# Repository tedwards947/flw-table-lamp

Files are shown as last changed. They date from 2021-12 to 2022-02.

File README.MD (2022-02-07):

# Intro
This is my 3D printed take on the Frank Lloyd Wright table lamp he designed for his house Taliesin in Wisconsin. I was inspired by seeing a wooden one in an art museum's gift shop. It was pretty but I didn't want to spend the $ to buy it, so my dad said, "Why don't you just make one?"--so I did! I didn't use any original drawings to help me with this design--it's a reverse engineering and re-imagining using 3D printed plastic instead of wood.

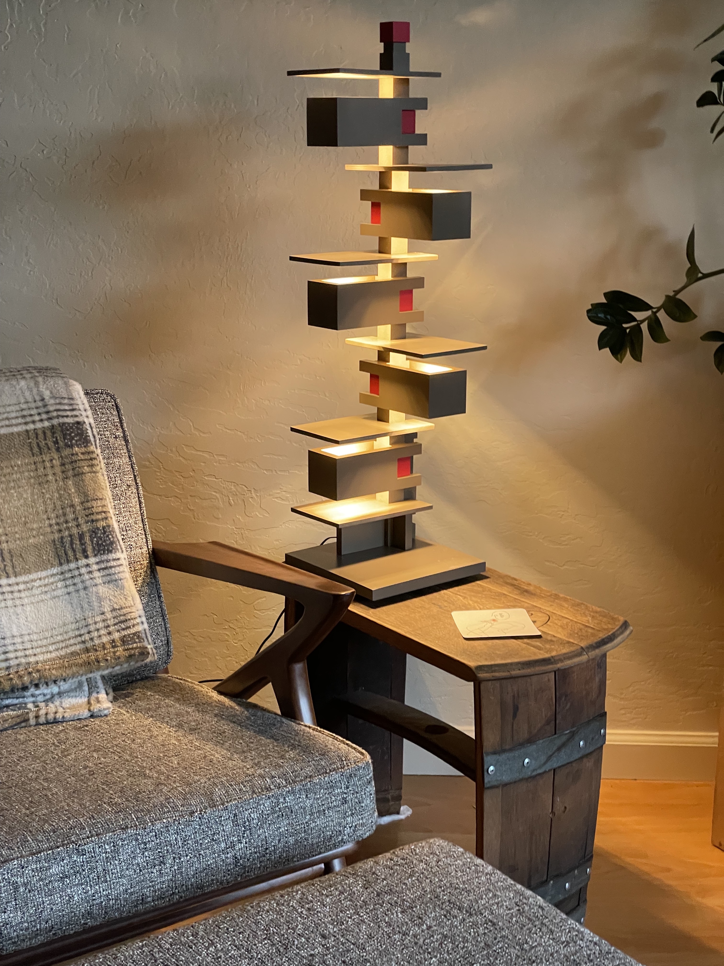
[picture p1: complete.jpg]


# Print Orientation
Here are the various parts you'll need to print, facing the orientation best suited for printing.

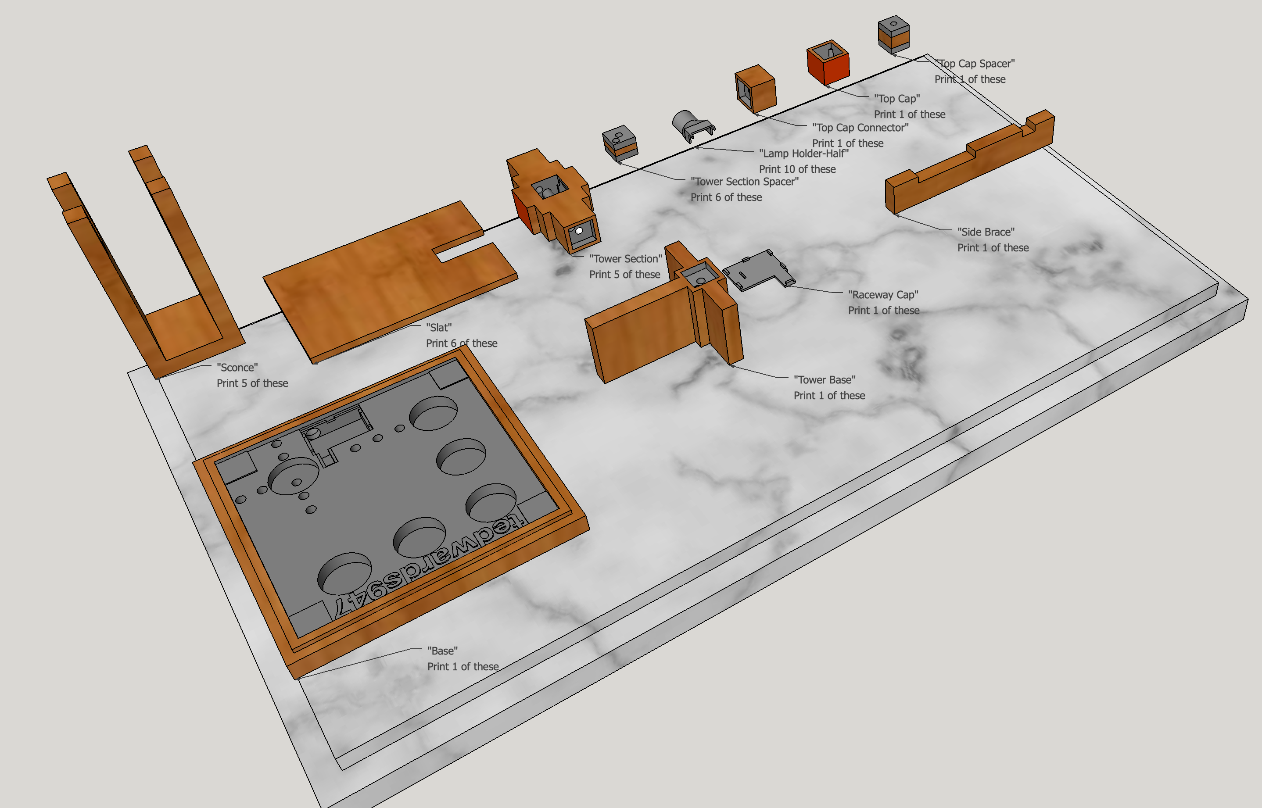
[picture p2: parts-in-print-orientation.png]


# Parts
Print the following number of each part:
<table>
    <tr><td><b>Part</b></td><td><b>Number</b></td></tr>
    <tr><td>Sconce</td><td>5</td></tr>
    <tr><td>Slat</td><td>6</td></tr>
    <tr><td>Tower Section</td><td>5</td></tr>
    <tr><td>Tower Section Spacer</td><td>6</td></tr>
    <tr><td>Lamp Holder</td><td>10</td></tr>
    <tr><td>Base</td><td>1</td></tr>
    <tr><td>Side Brace</td><td>1</td></tr>
    <tr><td>Top Cap</td><td>1</td></tr>
    <tr><td>Top Cap Spacer</td><td>1</td></tr>
    <tr><td>Top Cap Connector</td><td>1</td></tr>
    <tr><td>Raceway Cap</td><td>1</td></tr>
</table>

# Infill Suggestions
Feel free to deviate from these suggestions, but I tried to strike a balance between print speed, material usage, and strength.
<table>
    <tr><td><b>Part</b></td><td><b>Infill Percentage</b></td></tr>
    <tr><td>Sconce</td><td>5%</td></tr>
    <tr><td>Slat</td><td>5%</td></tr>
    <tr><td>Tower Section</td><td>15%</td></tr>
    <tr><td>Tower Section Spacer</td><td>15%</td></tr>
    <tr><td>Lamp Holder</td><td>15%</td></tr>
    <tr><td>Base</td><td>20%</td></tr>
    <tr><td>Side Brace</td><td>5-15%*</td></tr>
    <tr><td>Top Cap</td><td>15%</td></tr>
    <tr><td>Top Cap Spacer</td><td>15%</td></tr>
    <tr><td>Top Cap Connector</td><td>15%</td></tr>
    <tr><td>Raceway Cap</td><td>15%</td></tr>
</table>
*The majority was printed using 5%, except the area around the screw holes, which was printed with 15% for additional strength. 

# Required Hardware 
<table>
    <tr><td><b>Part/Link</b></td><td><b>Notes</b></td></tr>
    <tr><td><a href="https://www.homedepot.com/p/1-4-in-20-tpi-x-36-in-Zinc-Plated-Threaded-Rod-802217/204274011">Threaded Rod 20tpi 1/4" x 32"</a></td><td>Used for the "spine" of the lamp</td></tr>
    <tr><td><a href="https://www.amazon.com/dp/B08PZ38NC7?psc=1&ref=ppx_yo2_dt_b_product_details">12 volt E12 socket LED lightbulb</a></td><td><b>Make sure you use LED bulbs for low heat!</b></td></tr>
    <tr><td><a href="https://www.amazon.com/dp/B08S455YNF?ref=ppx_yo2_dt_b_product_details&th=1">E14 to E12 socket adapter</a></td><td>This is used to solder wires to to create a lamp socket</td></tr>
    <tr><td><a href="https://www.amazon.com/dp/B08H7SFXWM?psc=1&ref=ppx_yo2_dt_b_product_details">12 volt/3 amp wall power adapter</a></td><td>You can use whatever you like as long as you buy a correct cooresponding socket and it can handle the current the lamp draws</td></tr>
    <tr><td><a href="https://www.amazon.com/dp/B08CR6RTHP?psc=1&ref=ppx_yo2_dt_b_product_details">5.5x2.1mm jack socket</a></td><td>Use whatever you like, but make sure it'll fit in the hole in base.stl</td></tr>
    <tr><td><a href="https://www.amazon.com/dp/B06XPFDQBH?psc=1&ref=ppx_yo2_dt_b_product_details">Rubber feet for base</a></td><td>You can use whatever you like as long as it fits</td></tr>
    <tr><td><a href="https://www.homedepot.com/b/1-4-in/Fender-Washer/N-5yc1vZ1z0rvt6Z1z0ztd5">Fender washer 1/4" x 1.25"</a></td><td>One is used to secure the threaded rod to the spine of the lamp, but you're going to want to buy like 20 of these--there are cutouts in the base to add some with superglue to add additional mass to the base</td></tr>
    <tr><td><a href="https://www.homedepot.com/p/Everbilt-1-4-in-20-Stainless-Steel-Nylon-Lock-Nut-3-Pack-800131/204274167">1/4" 20tpi lock washers</a></td><td>You'll need 2 of these, one for the top and bottom</td></tr>
    <tr><td>1/4" x 5/8" Washer</td><td>Just 1 of these. Pick one up online or in your local hardware store</td></tr>
    <tr><td><a href="https://www.homedepot.com/p/3-Wire-Lever-Nut-10-Pack-60338741/318072979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">3-wire Lever-Nut wirenut</a></td><td>Not strictly needed, but I've designed the tower sections to incorporate them. You can wire it with a different connector (or just solder) if you want.</td></tr>
    <tr><td>Primer/filler spraypaint</td><td>Used to fill in rough surface created by 3d printing. About 3 cans.</td></tr>
    <tr><td>Paint or spraypaint of your choice</td><td>Any color will do! 3 cans or so.</td></tr>
    <tr><td>Accent color enamel paint</td><td>I've used red as in the image for the accent color. This is hand-painted on.</td></tr>
    <tr><td>Wet sandpaper & sanding block</td><td>Various grits, I've used 180 and 1000.</td></tr>
    <tr><td>Electrical wire (two colors)</td><td>Can be relatively thin, but make sure it has the capacity to handle up to 40 watts</td></tr>
</table>

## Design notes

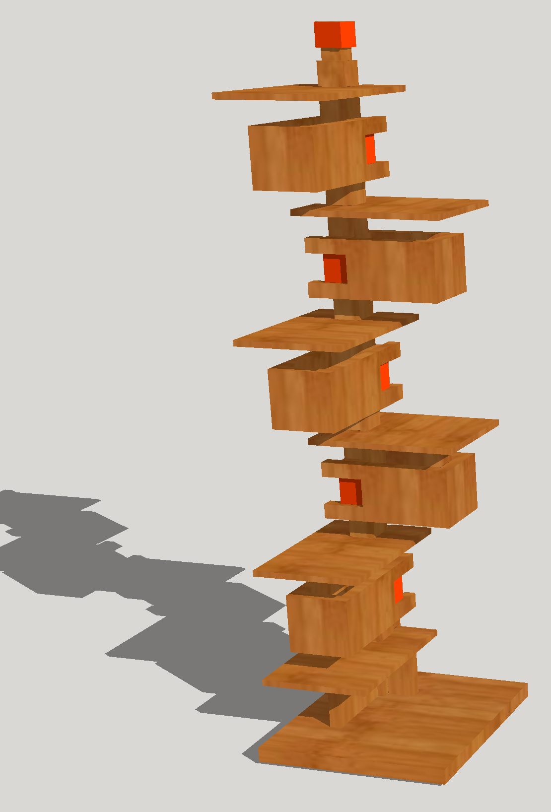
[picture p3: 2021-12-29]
screenshot.png

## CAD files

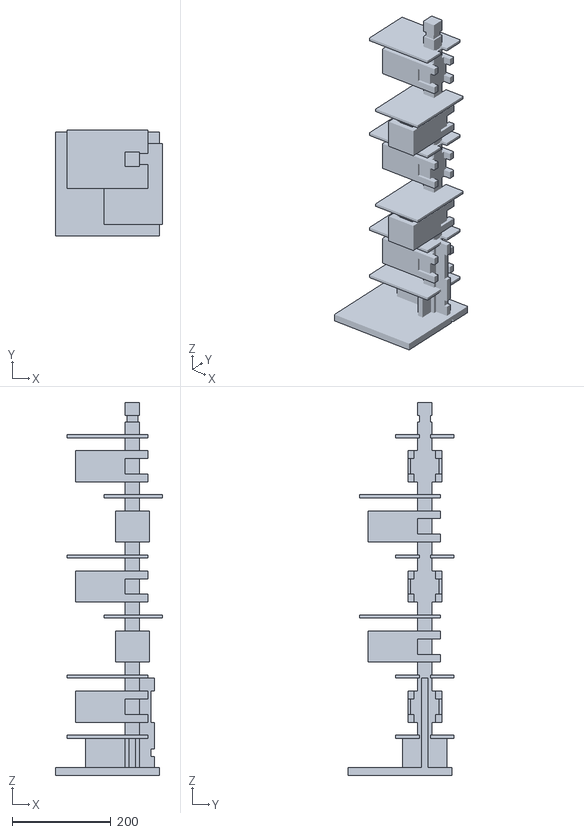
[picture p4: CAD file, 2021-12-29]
lamp.stl
216.6 x 214.7 x 754.1

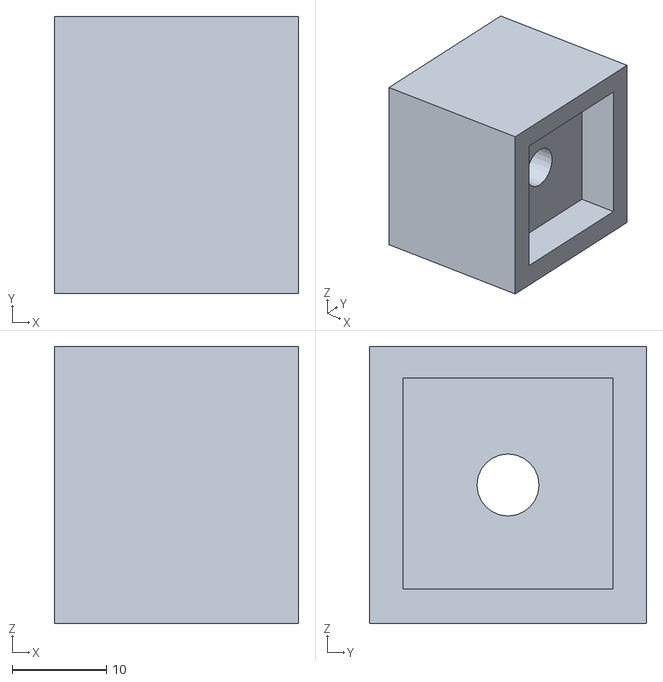
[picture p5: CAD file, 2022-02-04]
stl/top-cap-connector-1x.stl
26.0 x 29.5 x 29.5

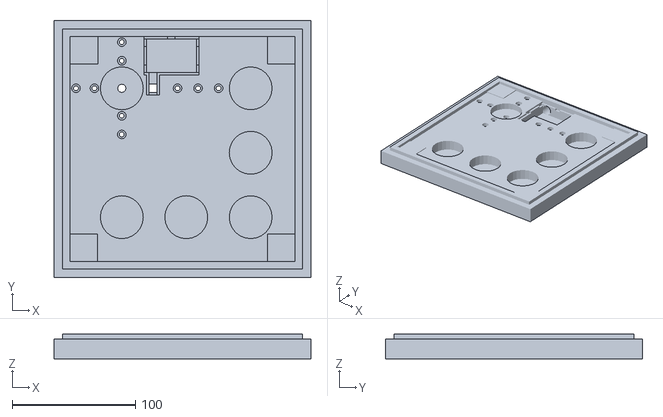
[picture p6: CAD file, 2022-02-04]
stl/base-1x.stl
208.8 x 208.8 x 20.0

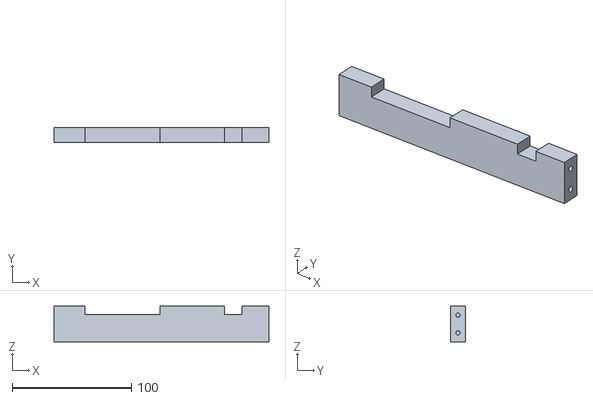
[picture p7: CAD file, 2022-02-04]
stl/side-brace-1x.stl
180.6 x 13.0 x 30.0

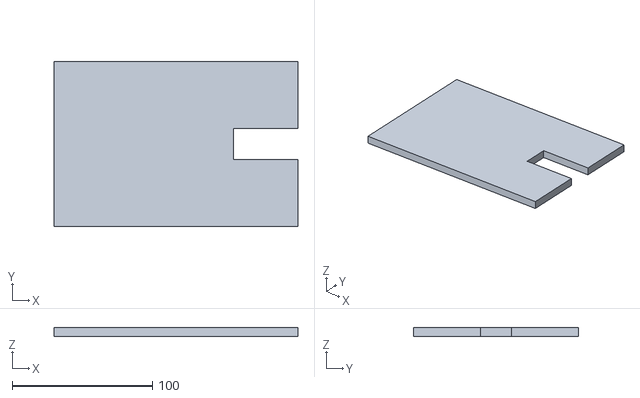
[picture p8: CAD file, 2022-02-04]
stl/slat-6x.stl
174.0 x 118.0 x 6.50

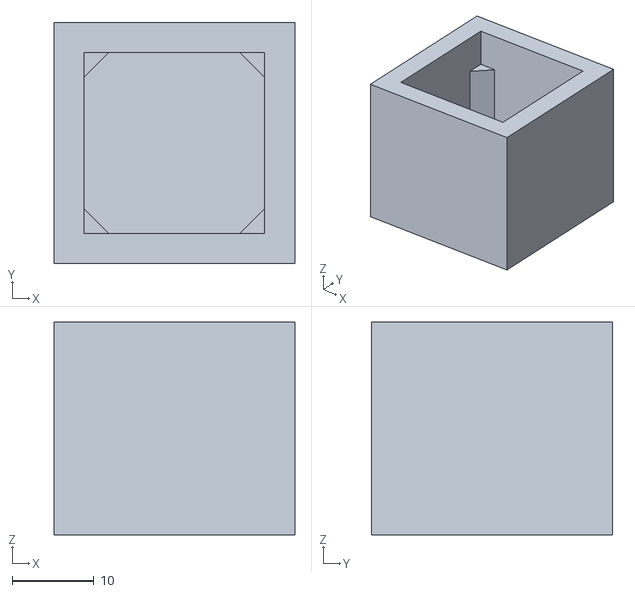
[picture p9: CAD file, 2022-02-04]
stl/top-cap-1x.stl
29.5 x 29.5 x 26.0

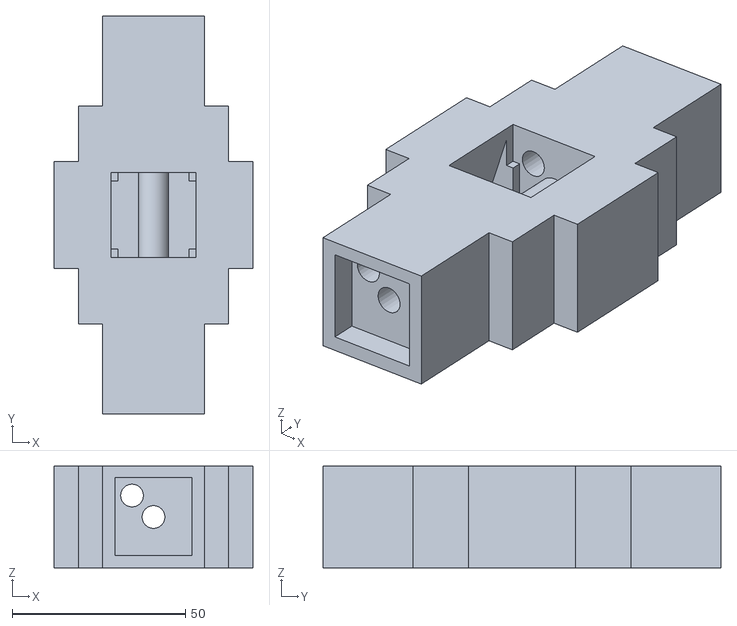
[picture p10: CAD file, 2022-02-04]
stl/tower-section-5x.stl
57.5 x 115.0 x 29.5

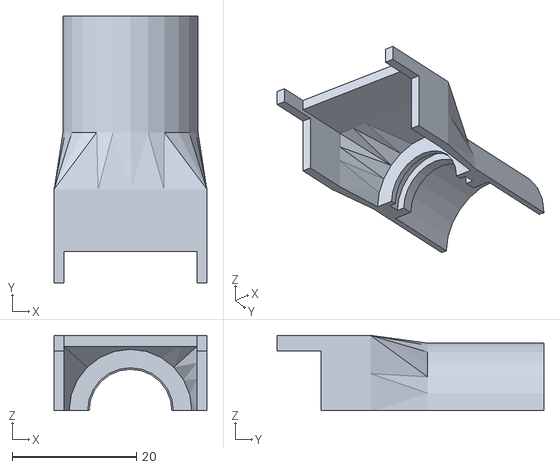
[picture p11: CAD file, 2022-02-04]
stl/lamp-holder-10x.stl
24.6 x 42.9 x 12.1

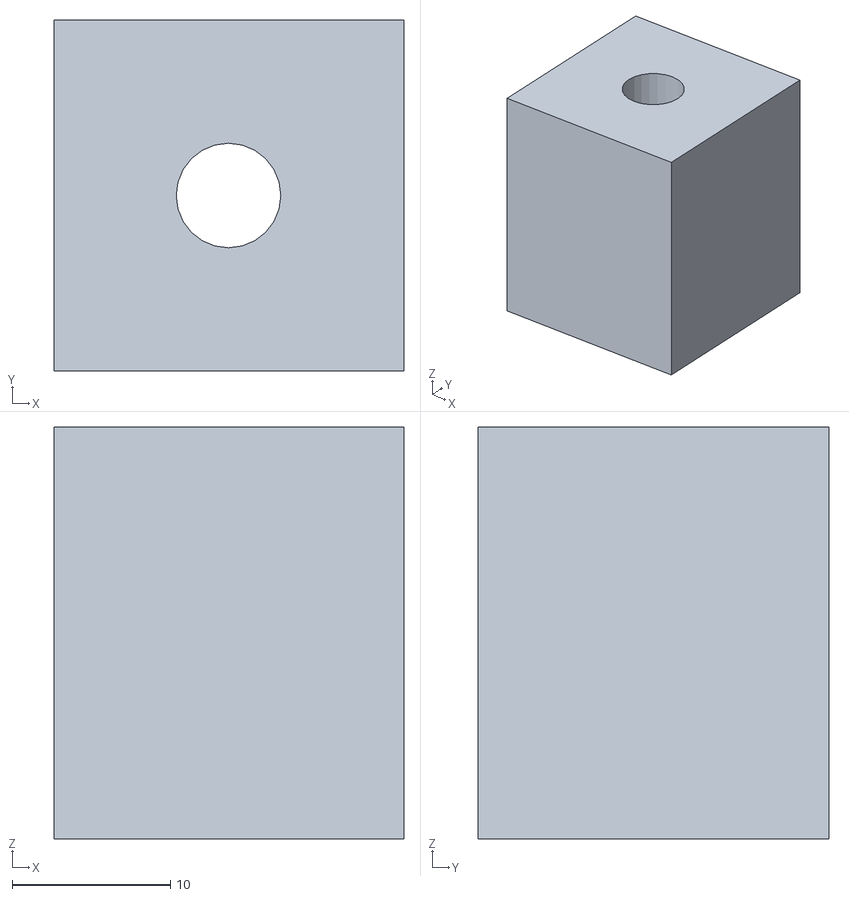
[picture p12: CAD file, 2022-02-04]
stl/top-cap-spacer-1x.stl
22.1 x 22.1 x 26.0

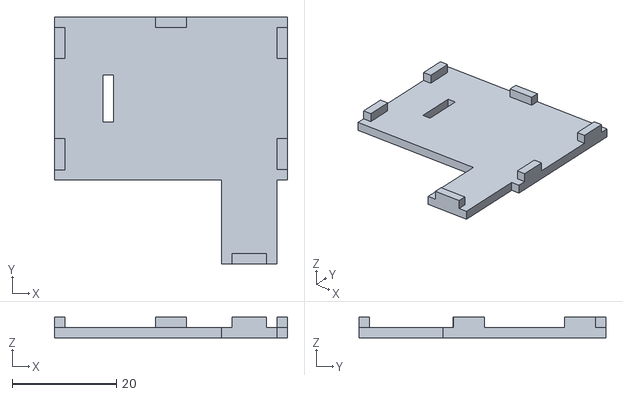
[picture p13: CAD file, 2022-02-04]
stl/raceway-cap-1x.stl
44.7 x 47.4 x 4.00

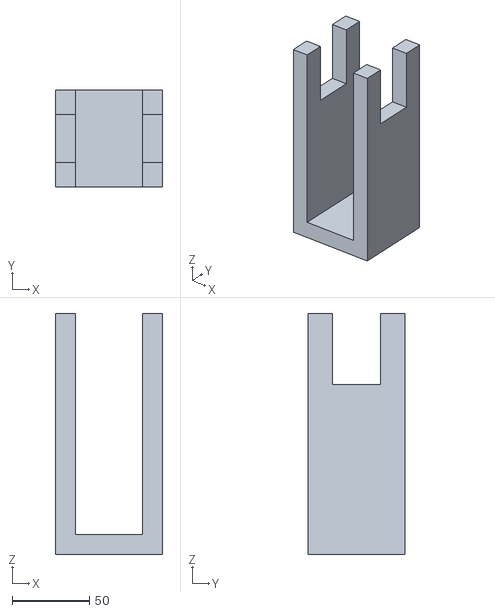
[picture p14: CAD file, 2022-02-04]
stl/sconce-5x.stl
69.5 x 63.0 x 156.0

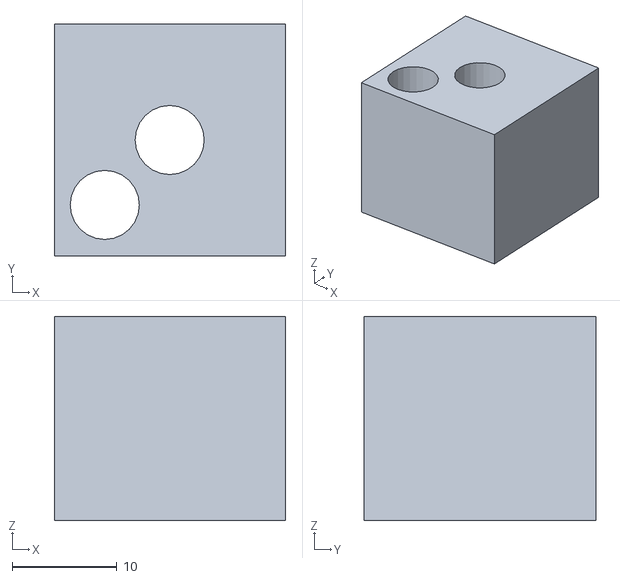
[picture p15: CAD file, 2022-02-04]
stl/tower-section-spacer-6x.stl
22.1 x 22.1 x 19.5

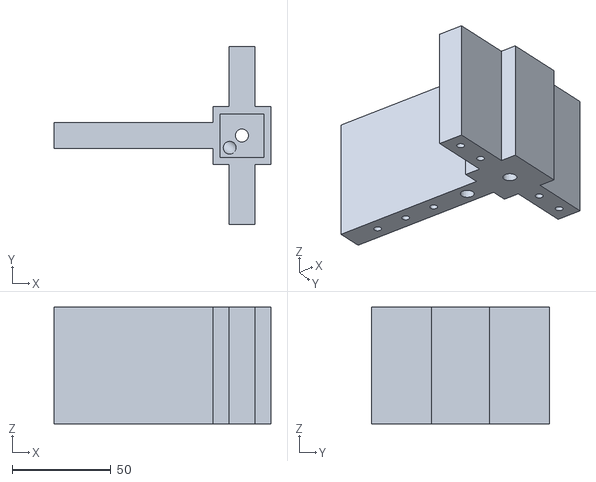
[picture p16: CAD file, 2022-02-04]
stl/tower-base-1x.stl
110.1 x 90.2 x 59.1

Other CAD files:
sliced-tower-main.skp

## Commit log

2021-12-29 initial commit after working on the airplane
    [lamp.skp]
2021-12-29 adding STL
    [lamp.stl]
2022-01-06 working a lot
    [lamp.skp, sliced-tower-main.skp]
2022-01-11 lamp holder
    [lamp.skp, sliced-tower-main.skp]
2022-01-21 updating cable race in tower base
    [sliced-tower-main.skp]
2022-01-21 updating cable raceway spline
    [sliced-tower-main.skp]
2022-01-24 adding more hardware, cable raceway tweak
    [sliced-tower-main.skp]
2022-01-25 adjusting dimensions post prototype
    [sliced-tower-main.skp]
2022-01-28 adding rubber feet
    [sliced-tower-main.skp]
